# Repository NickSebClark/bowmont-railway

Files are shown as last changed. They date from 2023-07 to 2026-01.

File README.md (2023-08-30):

banner

Source code and designs for my model railway.

### Contents

[arduino-command](arduino-command/) | 
Central controller with servo shield. Connects to PC and arduino-remote.

[arduino-remote](arduino-remote/) | Handheld remote to control the points.

[pc-control](pc-control/) | Python app to control the points on PC.

[anyrail](anyrail/) | Track plan.

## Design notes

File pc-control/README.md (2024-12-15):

# Bowmont Railway PC Control



Uses pygame for animation. Communicates with Arduino using PySerial

Top-level: [main.py](pc_control/main.py).

Settings can be found in [settings.toml](settings.toml).

## Install

Dependencies are managed with [uv](https://docs.astral.sh/uv/). cd to the directory and get started with:

```shell
uv run main
```

The project is configured as a package. This tells uv to install pc_control as an editable package in the environment. This way, imports can always be relative to this package.

main.py is added as a script so we can access it easily with uv run.

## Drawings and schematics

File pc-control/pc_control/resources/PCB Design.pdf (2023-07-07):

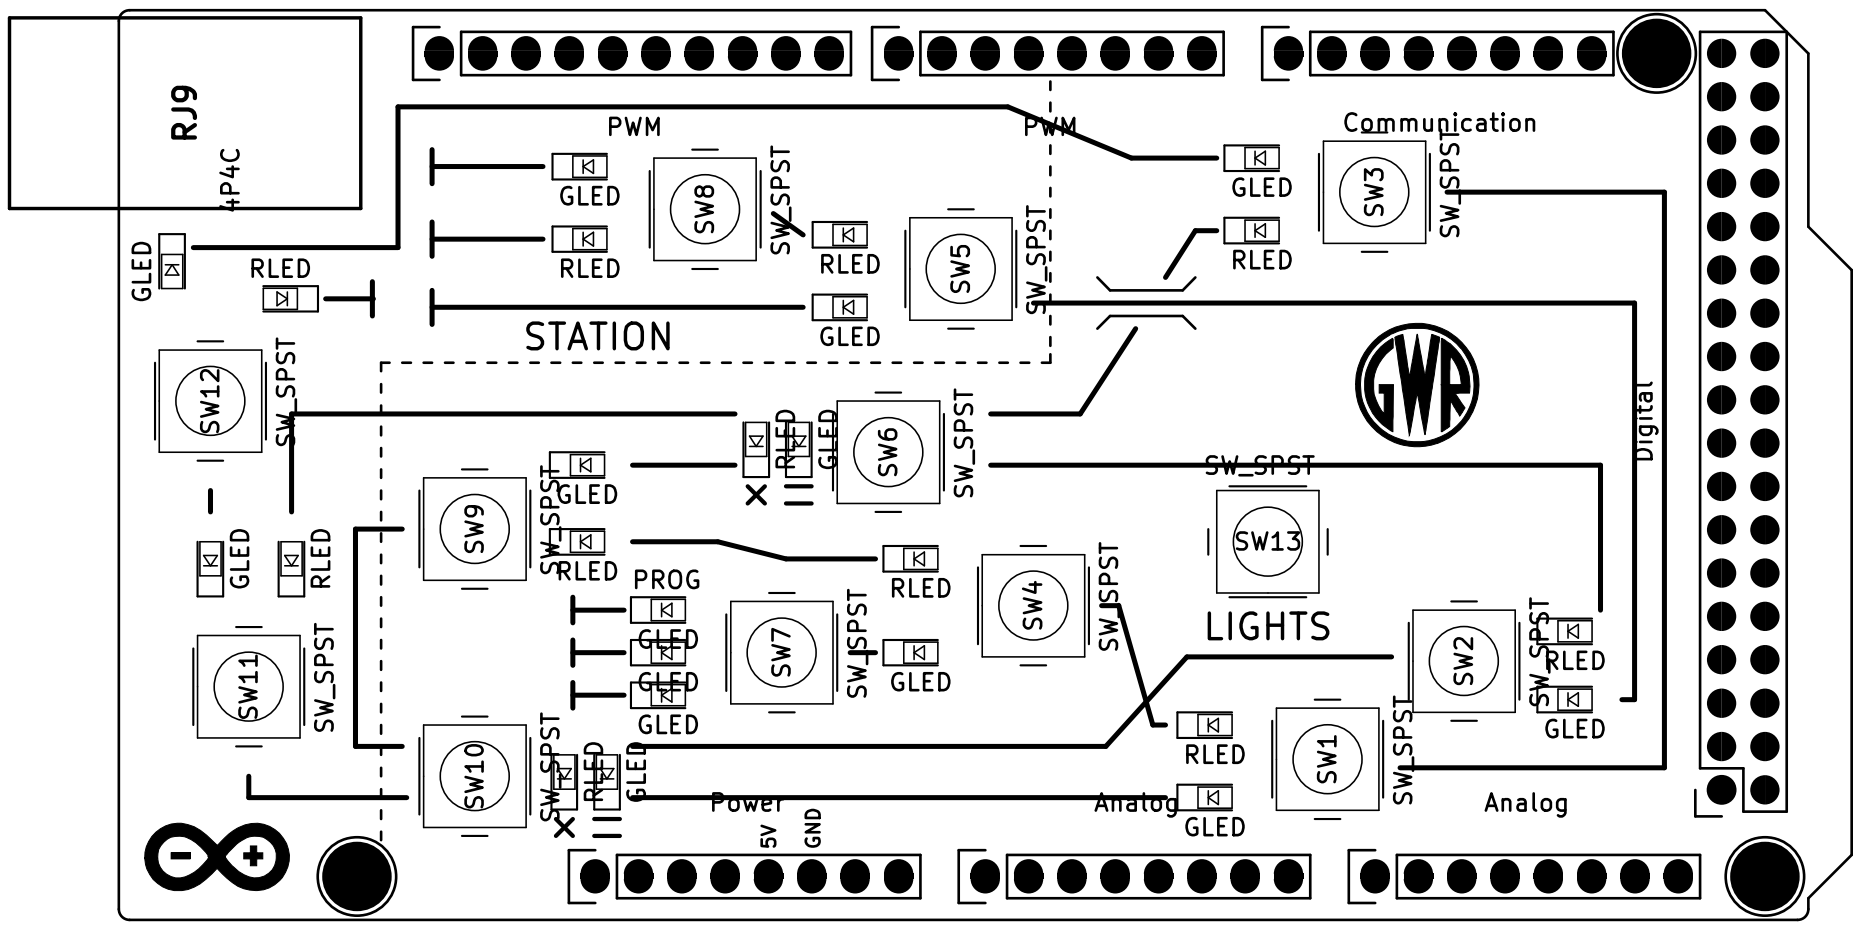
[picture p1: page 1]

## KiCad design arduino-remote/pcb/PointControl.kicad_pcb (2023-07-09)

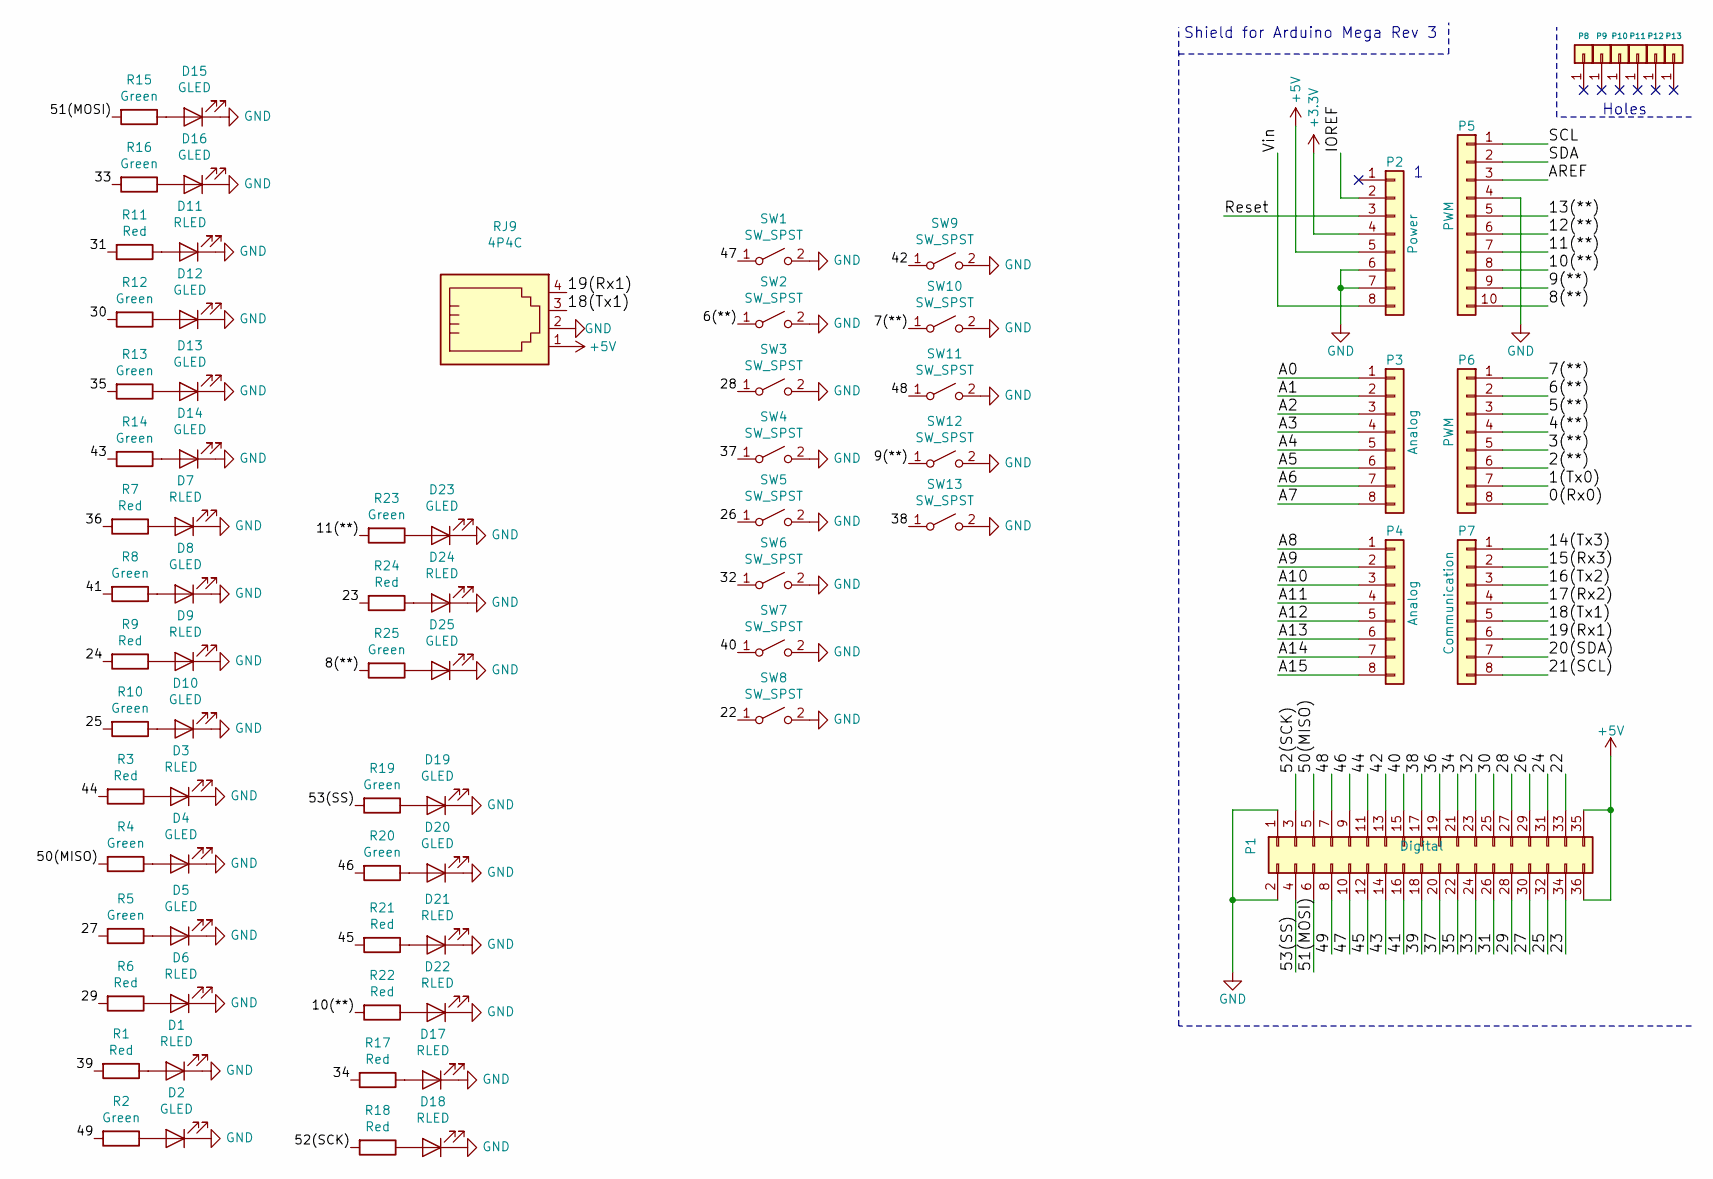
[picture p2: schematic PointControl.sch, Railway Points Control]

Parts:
D1, D3, D6, D7, D9, D11, D17, D18, D21, D22, D24: RLED; LED_0805_HandSoldering
D2, D4, D5, D8, D10, D12, D13, D14, D15, D16, D19, D20, D23, D25: GLED; LED_0805_HandSoldering
P1: Digital; Socket_Strip_Arduino_2x18
P2: Power; Socket_Strip_Arduino_1x08
P3, P4: Analog; Socket_Strip_Arduino_1x08
P5: PWM; Socket_Strip_Arduino_1x10
P6: PWM; Socket_Strip_Arduino_1x08
P7: Communication; Socket_Strip_Arduino_1x08
P8, P9, P10, P11, P12, P13: CONN_01X01; Arduino_1pin
R1, R3, R6, R7, R9, R11, R17, R18, R21, R22, R24: Red; R_0805_HandSoldering
R2, R4, R5, R8, R10, R12, R13, R14, R15, R16, R19, R20, R23, R25: Green; R_0805_HandSoldering
RJ9: 4P4C; MHRJJ44NFRA
SW1, SW2, SW3, SW4, SW5, SW6, SW7, SW8, SW9, SW10, SW11, SW12, SW13: SW_SPST; SW_PUSH_6mm

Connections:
+3V3: P2.4
+5V: P1.35, P1.36, P2.5, RJ9.1
/0(Rx0): P6.8
/1(Tx0): P6.7
/2(**): P6.6
/3(**): P6.5
/4(**): P6.4
/5(**): P6.3
/6(**): P6.2, SW2.1 (A)
/7(**): P6.1, SW10.1 (A)
/8(**): P5.10, R25.2
/9(**): P5.9, SW12.1 (A)
/10(**): P5.8, R22.2
/11(**): P5.7, R23.2
/12(**): P5.6
/13(**): P5.5
/14(Tx3): P7.1
/15(Rx3): P7.2
/16(Tx2): P7.3
/17(Rx2): P7.4
/18(Tx1): P7.5, RJ9.3
/19(Rx1): P7.6, RJ9.4
/20(SDA): P7.7
/21(SCL): P7.8
/22: P1.33, SW8.1 (A)
/23: P1.34, R24.2
/24: P1.31, R9.2
/25: P1.32, R10.2
/26: P1.29, SW5.1 (A)
/27: P1.30, R5.2
/28: P1.27, SW3.1 (A)
/29: P1.28, R6.2
/30: P1.25, R12.2
/31: P1.26, R11.2
/32: P1.23, SW6.1 (A)
/33: P1.24, R16.2
/34: P1.21, R17.2
/35: P1.22, R13.2
/36: P1.19, R7.2
/37: P1.20, SW4.1 (A)
/38: P1.17, SW13.1 (A)
/39: P1.18, R1.2
/40: P1.15, SW7.1 (A)
/41: P1.16, R8.2
/42: P1.13, SW9.1 (A)
/43: P1.14, R14.2
/44: P1.11, R3.2
/45: P1.12, R21.2
/46: P1.9, R20.2
/47: P1.10, SW1.1 (A)
/48: P1.7, SW11.1 (A)
/49: P1.8, R2.2
/50(MISO): P1.5, R4.2
/51(MOSI): P1.6, R15.2
/52(SCK): P1.3, R18.2
/53(SS): P1.4, R19.2
/A0: P3.1
/A1: P3.2
/A2: P3.3
/A3: P3.4
/A4: P3.5
/A5: P3.6
/A6: P3.7
/A7: P3.8
/A8: P4.1
/A9: P4.2
/A10: P4.3
/A11: P4.4
/A12: P4.5
/A13: P4.6
/A14: P4.7
/A15: P4.8
/AREF: P5.3
/IOREF: P2.2
/Reset: P2.3
/SCL: P5.1
/SDA: P5.2
/Vin: P2.8
GND: D1.1 (K), D2.1 (K), D3.1 (K), D4.1 (K), D5.1 (K), D6.1 (K), D7.1 (K), D8.1 (K), D9.1 (K), D10.1 (K), D11.1 (K), D12.1 (K), D13.1 (K), D14.1 (K), D15.1 (K), D16.1 (K), D17.1 (K), D18.1 (K), D19.1 (K), D20.1 (K), D21.1 (K), D22.1 (K), D23.1 (K), D24.1 (K), D25.1 (K), P1.1, P1.2, P2.6, P2.7, P5.4, RJ9.2, SW1.2 (B), SW2.2 (B), SW3.2 (B), SW4.2 (B), SW5.2 (B), SW6.2 (B), SW7.2 (B), SW8.2 (B), SW9.2 (B), SW10.2 (B), SW11.2 (B), SW12.2 (B), SW13.2 (B)
unnamed: D1.2 (A), R1.1
unnamed: D2.2 (A), R2.1
unnamed: D3.2 (A), R3.1
unnamed: D4.2 (A), R4.1
unnamed: D5.2 (A), R5.1
unnamed: D6.2 (A), R6.1
unnamed: D7.2 (A), R7.1
unnamed: D8.2 (A), R8.1
unnamed: D9.2 (A), R9.1
unnamed: D10.2 (A), R10.1
unnamed: D11.2 (A), R11.1
unnamed: D12.2 (A), R12.1
unnamed: D13.2 (A), R13.1
unnamed: D14.2 (A), R14.1
unnamed: D15.2 (A), R15.1
unnamed: D16.2 (A), R16.1
unnamed: D17.2 (A), R17.1
unnamed: D18.2 (A), R18.1
unnamed: D19.2 (A), R19.1
unnamed: D20.2 (A), R20.1
unnamed: D21.2 (A), R21.1
unnamed: D22.2 (A), R22.1
unnamed: D23.2 (A), R23.1
unnamed: D24.2 (A), R24.1
unnamed: D25.2 (A), R25.1

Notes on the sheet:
Shield for Arduino Mega Rev 3
Holes

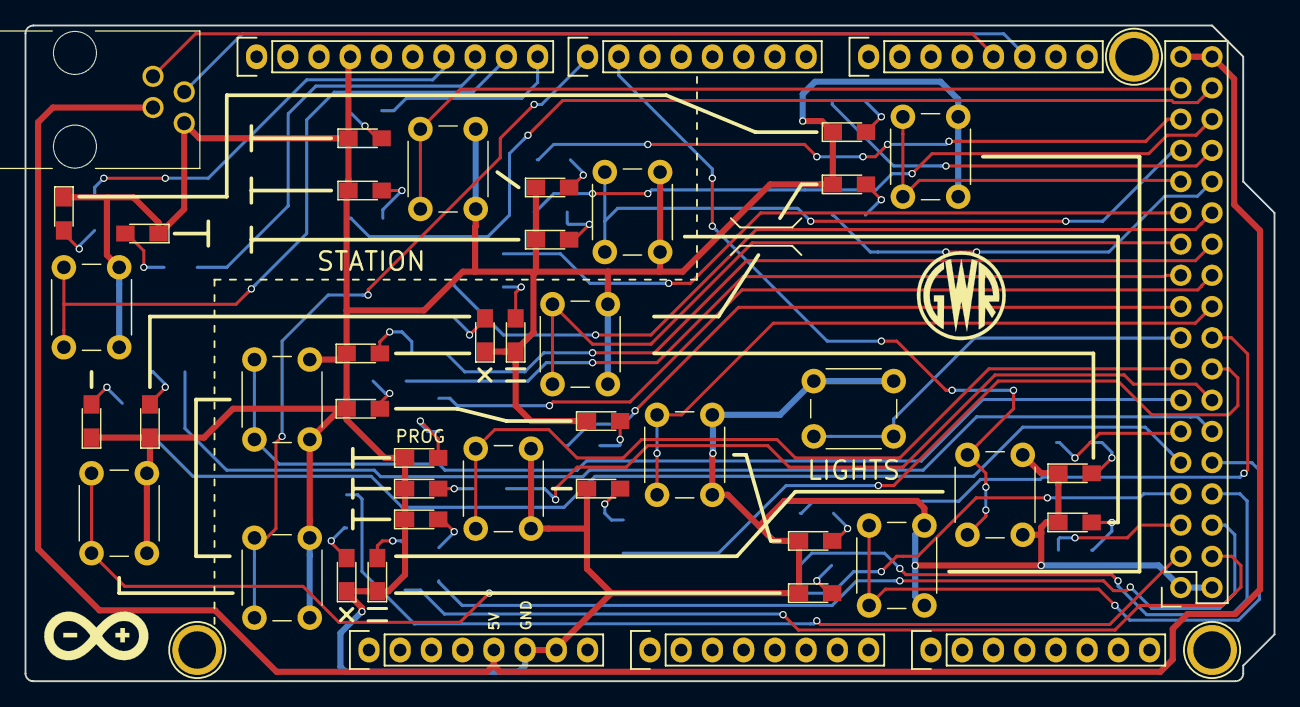
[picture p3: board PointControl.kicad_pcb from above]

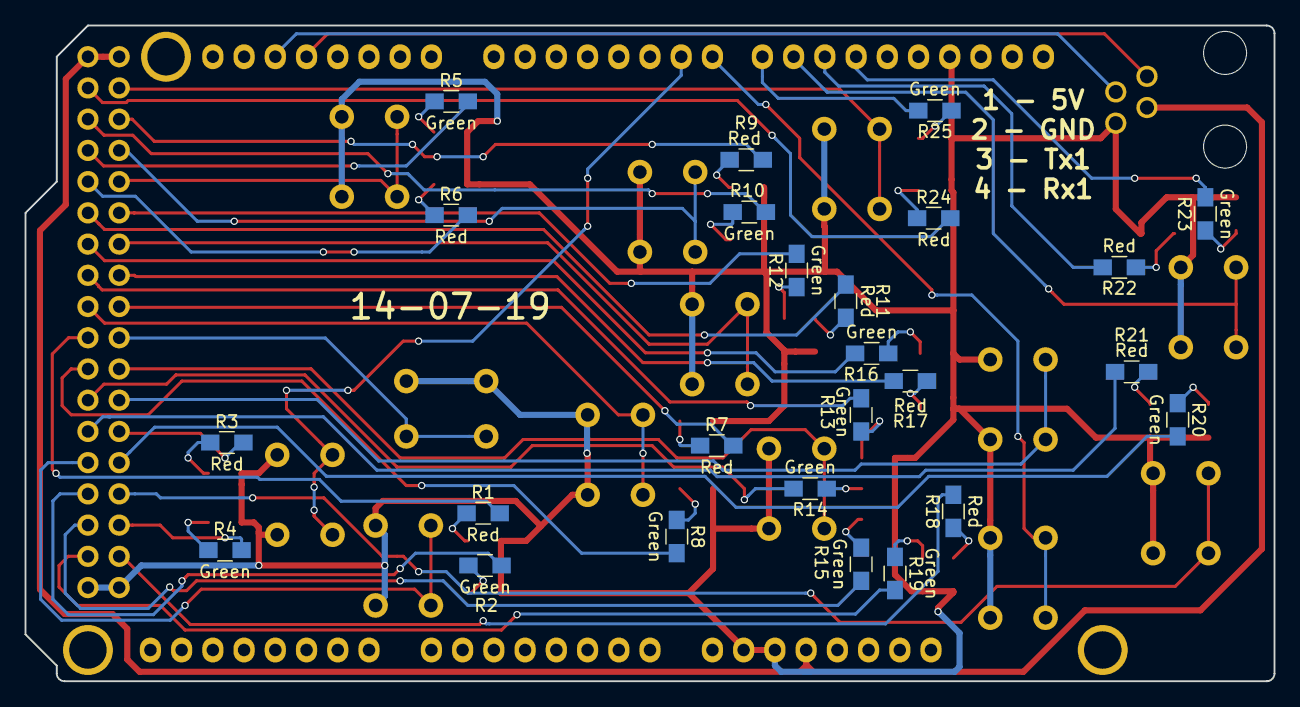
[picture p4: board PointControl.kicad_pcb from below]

Board: 2 copper layers, 101.6 x 53.3 mm, 74 parts (25 on the bottom side), 67 nets.

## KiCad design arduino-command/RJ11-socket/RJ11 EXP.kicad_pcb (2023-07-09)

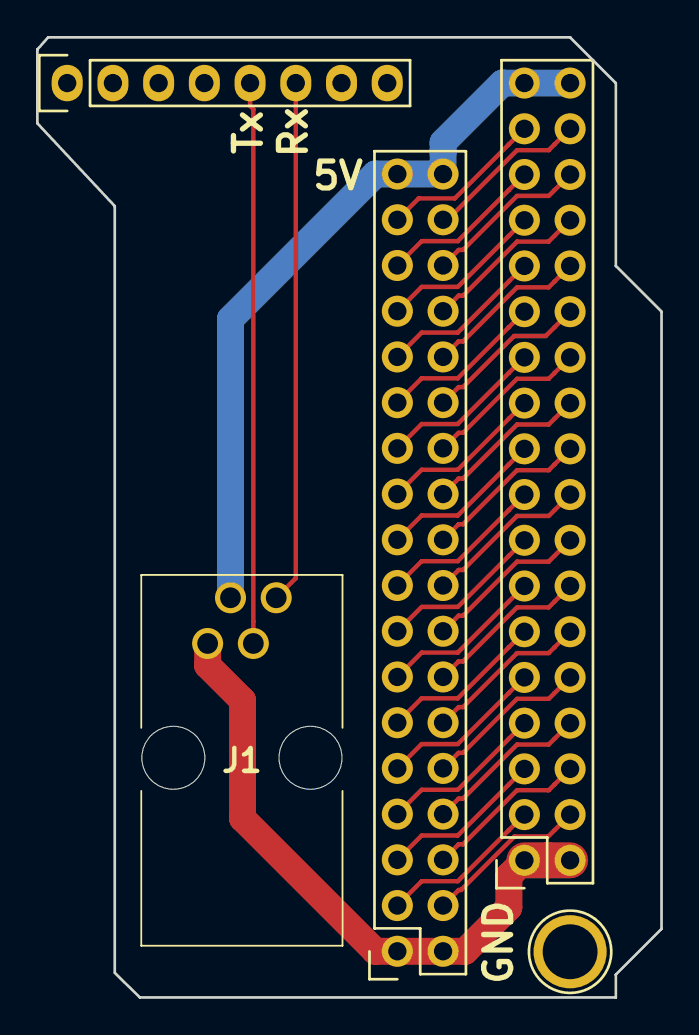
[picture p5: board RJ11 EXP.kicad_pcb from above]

Board: 2 copper layers, 34.7 x 53.3 mm, 5 parts (0 on the bottom side), 36 nets.

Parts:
J1: RJ9; MHRJJ44NFRA
P1, P14: Digital; Socket_Strip_Arduino_2x18
P7: Communication; Socket_Strip_Arduino_1x08
P10: CONN_01X01; Arduino_1pin

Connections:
+5V: J1.4, P1.35, P1.36, P14.35, P14.36
/18(Tx1): J1.1, P7.5
/19(Rx1): J1.2, P7.6
/22: P1.33, P14.33
/23: P1.34, P14.34
/24: P1.31, P14.31
/25: P1.32, P14.32
/26: P1.29, P14.29
/27: P1.30, P14.30
/28: P1.27, P14.27
/29: P1.28, P14.28
/30: P1.25, P14.25
/31: P1.26, P14.26
/32: P1.23, P14.23
/33: P1.24, P14.24
/34: P1.21, P14.21
/35: P1.22, P14.22
/36: P1.19, P14.19
/37: P1.20, P14.20
/38: P1.17, P14.17
/39: P1.18, P14.18
/40: P1.15, P14.15
/41: P1.16, P14.16
/42: P1.13, P14.13
/43: P1.14, P14.14
/44: P1.11, P14.11
/45: P1.12, P14.12
/46: P1.9, P14.9
/47: P1.10, P14.10
/48: P1.7, P14.7
/49: P1.8, P14.8
/50(MISO): P1.5, P14.5
/51(MOSI): P1.6, P14.6
/52(SCK): P1.3, P14.3
/53(SS): P1.4, P14.4
GND: J1.3, P1.1, P1.2, P14.1, P14.2

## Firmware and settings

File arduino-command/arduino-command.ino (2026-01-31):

#include <Adafruit_PWMServoDriver.h>

#include <TimerThree.h>

#include <Wire.h>
#include <Adafruit_PWMServoDriver.h>

#define NBR_POINTS 15

#define Control_switch 44


// min = 200
// max = 300 

// the counter number for each servo
// look at the diagram on Python. The buttons are labelled
#define servo_0 14   // Button 0
#define servo_1 6   // Button 1
#define servo_2 8   // Button 2
#define servo_3 2  // Button 3
#define servo_4 1  // Button 3
#define servo_5 15   // Button 4 #TESTTEST
#define servo_6 4  // Button 5
#define servo_7 5  // Button 5
#define servo_8 10  // Button 6
#define servo_9 9   // Button 6
#define servo_10 7  // Button 7 INCREMENT TEST
#define servo_11 3  // Button 8
#define servo_12 11 // Button 9
#define servo_13 12 // Button 10
#define servo_14 13 // Button 11

#define servo_0_pos0 326
#define servo_1_pos0 275
#define servo_2_pos0 340
#define servo_3_pos0 350
#define servo_4_pos0 200
#define servo_5_pos0 275
#define servo_6_pos0 350
#define servo_7_pos0 362
#define servo_8_pos0 279
#define servo_9_pos0 324
#define servo_10_pos0 395
#define servo_11_pos0 350
#define servo_12_pos0 276
#define servo_13_pos0 275
#define servo_14_pos0 290

#define servo_0_pos1 276
#define servo_1_pos1 376
#define servo_2_pos1 278
#define servo_3_pos1 200
#define servo_4_pos1 275
#define servo_5_pos1 358
#define servo_6_pos1 285
#define servo_7_pos1 299
#define servo_8_pos1 324
#define servo_9_pos1 276
#define servo_10_pos1 275
#define servo_11_pos1 283
#define servo_12_pos1 340
#define servo_13_pos1 350
#define servo_14_pos1 340

Adafruit_PWMServoDriver pwm = Adafruit_PWMServoDriver();

char inCmd[6];
int cmdPos = 0;

int pointStatus[NBR_POINTS];
int pointServo[NBR_POINTS] = {servo_0, servo_1, servo_2, servo_3, servo_4, servo_5, servo_6, servo_7, servo_8, servo_9, servo_10, servo_11, servo_12, servo_13, servo_14};
int pointPos0[NBR_POINTS] = {servo_0_pos0, servo_1_pos0, servo_2_pos0, servo_3_pos0, servo_4_pos0, servo_5_pos0, servo_6_pos0, servo_7_pos0, servo_8_pos0, servo_9_pos0, servo_10_pos0, servo_11_pos0, servo_12_pos0, servo_13_pos0, servo_14_pos0};
int pointPos1[NBR_POINTS] = {servo_0_pos1, servo_1_pos1, servo_2_pos1, servo_3_pos1, servo_4_pos1, servo_5_pos1, servo_6_pos1, servo_7_pos1, servo_8_pos1, servo_9_pos1, servo_10_pos1, servo_11_pos1, servo_12_pos1, servo_13_pos1, servo_14_pos1};
int point_pair[NBR_POINTS] = {0, 0, 0, 1, -1, 0, 0, 0, 1, -1, 0, 0, 0, 0, 0}; // shows the offset, if any, to a partner in a point pair.
int pointPos[NBR_POINTS];

boolean stringRecieved = false;

String syncString;

void incrementPosition(int point)
{
  pointPos[point]++;

  pwm.setPWM(pointServo[point], 0, pointPos[point]);

  Serial.print("<Increment point in Arduino, Point: ");
  Serial.print(point);
  Serial.print(" Val: ");
  Serial.print(pointPos[point]);
  Serial.print(">\n");
}

void decrementPosition(int point)
{
  pointPos[point]--;

  pwm.setPWM(pointServo[point], 0, pointPos[point]);

  Serial.print("<Decrement point in Arduino, Point: ");
  Serial.print(point);
  Serial.print(" Val: ");
  Serial.print(pointPos[point]);
  Serial.print(">\n");
}

void setup()
{
  Serial.begin(9600); // init comm
  Serial1.begin(9600);

  pwm.begin();
  pwm.setPWMFreq(50);

  memcpy(pointPos, pointPos0, sizeof(pointPos0));

  for (int i = 0; i < NBR_POINTS; i++)
  {
    pointStatus[i] = 0;
    setPoint(i, false);
  }
  syncData();

  Timer3.initialize(20000000);
  Timer3.attachInterrupt(sendHeartBeat);
}

void loop()
{
}

void parseString()
{
  Serial.print("<Parsing Input String>\n");
  
  int point_index;

  switch (inCmd[0])
  {
  case 'p':

    point_index = indexFromString();

    // set the point pair too if it exists. We only update on the seconf of the pair
    if (point_pair[point_index] != 0){ 
      setPoint(point_index, false);
      setPoint(point_index + point_pair[point_index], true);
    }
    else
      setPoint(point_index, true);

    break;
  case 's':
    setSignal(inCmd[2]);
    break;
  case 'l':
    toggleLights();
    break;
  case 'c':
    sendHeartBeat();
    break;
  case 'r':
    syncData();
    break;
  case 'i':
    incrementPosition(indexFromString());
    break;
  case 'd':
    decrementPosition(indexFromString());
    break;
  default:
    Serial.println("<Command not found>");
    break;
  }
}

int indexFromString()
{
  String s;
  if (cmdPos > 2)
  { // two character number
    s = String(inCmd[1]) + String(inCmd[2]);
    return s.toInt();
  }
  else
    return (int)inCmd[1] - 48;
}



void serialEvent1()
{
  while (Serial1.available())
  {
    int i;

    char inChar = (char)Serial1.read();

    // add it to the inputString:
    inCmd[cmdPos] = inChar;
    cmdPos++;

    // if the incoming character is a newline, we have a whole command. Do something.
    if (inChar == '\n')
    {
      Serial.println("<Serial-1 Recieved>");
      for (i = 0; i < cmdPos; i++)
      {
        Serial.print(inCmd[i]);
      }
      parseString();
      cmdPos = 0;
    }
  }
}

void serialEvent()
{ // reads from the serial port
  while (Serial.available())
  {
    int i;
    char inChar = (char)Serial.read();

    // add it to the inputString:
    inCmd[cmdPos] = inChar;
    cmdPos++;

    // if the incoming character is a newline, we have a whole command. Do something.
    if (inChar == '\n')
    {
      Serial.println("<Serial Recieved>");
      for (i = 0; i < cmdPos; i++)
      {
        Serial.print(inCmd[i]);
      }
      parseString();
      cmdPos = 0;
    }
  }
}

void sendHeartBeat()
{
  Serial.print("<ID: 18/01/25 v2.3>\n");
}

void setPoint(int point, bool sync)
{ // toggles status of point

  if (pointServo[point] > -2)
  {
    if (pointStatus[point])
    {
      Serial.print("<Setting point in Arduino, Point: ");
      Serial.print(point);
      Serial.print(" Val: ");
      Serial.print(pointPos0[point]);
      Serial.print(">\n");
      pwm.setPWM(pointServo[point], 0, pointPos0[point]);
      pointStatus[point] = 0;
      pointPos[point] = pointPos0[point];
    }
    else
    {
      Serial.print("<Setting point in Arduino, Point: ");
      Serial.print(point);
      Serial.print(" Val: ");
      Serial.print(pointPos1[point]);
      Serial.print(">\n");
      pwm.setPWM(pointServo[point], 0, pointPos1[point]);
      pointStatus[point] = 1;
      pointPos[point] = pointPos1[point];
    }
  }
  delay(1000);
  pwm.setPWM(pointServo[point], 0, 0);

  if (sync){
    syncData();
  }
}

void syncData()
{
  syncString = "S";
  for (int k = 0; k < NBR_POINTS; k++)
  {
    syncString = syncString + String(pointStatus[k]);
  }
  // send to both serial ports so PC/controller swap is seamless.
  Serial.println(syncString);
  Serial1.println(syncString);
}

void setSignal(int sig)
{
  Serial.println("<Signals...>");
  syncData();
}

void toggleLights()
{
  Serial.println("<Lights Toggled>");
  syncData();
}

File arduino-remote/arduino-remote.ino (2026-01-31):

#define NBR_SERVOS 15
#define NBR_POINT_BUTTONS 12

// led pins for each point
int ledpins[][2] = {{10, 11},
                    {45, 46},
                    {34, 33},
                    {52, 53},
                    {8, 23},
                    {-1, -1},
                    {31, 30},
                    {24, 25},
                    {36, 41},
                    {29, 27},
                    {39, 49},
                    {44, 50}};

// LED pins for the tristate button
int ledpins_tri[] = {35, 43, 51};
int button_pins[] = {9, 48, 42, 7, 22, 40, 32, 26, 37, 28, 47, 6, 38};

const int flash_wait = 200;

int servo_point[] = {0, 1, 2, 3, 3, 4, 5, 5, 6, 6, 7, 8, 9, 10, 11}; // defines which point a particular servo is changing. I.e. when a servo changes which light should we change.
int point_servo[] = {0, 1, 2, 3, 5, 6, 8, 10, 11, 12, 13, 14};       // what servo to switch for a particular point, the controller handles point pairs)
int servo_6_set;
int servo_7_set;

int i = 0;

int buttonState[NBR_POINT_BUTTONS + 1];     // the current reading from the input pin
int lastButtonState[NBR_POINT_BUTTONS + 1]; // the previous reading from the input pin

// the following variables are unsigned longs because the time, measured in
// milliseconds, will quickly become a bigger number than can be stored in an int.
unsigned long lastDebounceTime[NBR_POINT_BUTTONS + 1]; // the last time the output pin was toggled
unsigned long debounceDelay = 100;                     // the debounce time; increase if the output flickers
unsigned long previousMillis = 0;                      // will store last time LED was updated

char inCmd[25];
int cmdPos = 0;
bool startup = true;

void setup()
{

  // set the digital pin as output:
  for (i = 0; i < NBR_POINT_BUTTONS; i++)
  {
    pinMode(ledpins[i][0], OUTPUT);
    digitalWrite(ledpins[i][0], LOW);

    pinMode(ledpins[i][1], OUTPUT);
    digitalWrite(ledpins[i][1], LOW);

    pinMode(ledpins_tri[0], OUTPUT);
    digitalWrite(ledpins_tri[0], LOW);
    pinMode(ledpins_tri[1], OUTPUT);
    digitalWrite(ledpins_tri[1], LOW);
    pinMode(ledpins_tri[2], OUTPUT);
    digitalWrite(ledpins_tri[2], LOW);

    pinMode(button_pins[i], INPUT_PULLUP);
  }

  pinMode(button_pins[NBR_POINT_BUTTONS], INPUT_PULLUP);

  circleLights();

  // set all the button states to false
  memset(lastButtonState, 0, sizeof(lastButtonState));

  // initialize serial:
  Serial1.begin(9600);
  Serial.begin(9600);

  requestSync();
}

void requestSync()
{ // send a message to the points controller to request a synchronisation
  Serial1.write("r\n");
}

void flashLights(int wait)
{
  for (i = 0; i < NBR_POINT_BUTTONS; i++)
  {
    digitalWrite(ledpins[i][0], HIGH);
    digitalWrite(ledpins[i][1], HIGH);
    if (i == 5)
    {
      digitalWrite(ledpins_tri[0], HIGH);
      digitalWrite(ledpins_tri[1], HIGH);
      digitalWrite(ledpins_tri[2], HIGH);
    }
  }

  delay(wait);

  for (i = 0; i < NBR_POINT_BUTTONS; i++)
  {
    digitalWrite(ledpins[i][0], LOW);
    digitalWrite(ledpins[i][1], LOW);
    if (i == 5)
    {
      digitalWrite(ledpins_tri[0], LOW);
      digitalWrite(ledpins_tri[1], LOW);
      digitalWrite(ledpins_tri[2], LOW);
    }
  }

  delay(wait);
}

void circleLights()
{

  for (i = 0; i < NBR_POINT_BUTTONS; i++)
  { // circle around all the lights
    if (i == 5)
    {
      digitalWrite(ledpins_tri[0], LOW);
      digitalWrite(ledpins_tri[1], LOW);
      digitalWrite(ledpins_tri[2], LOW);
    }
    else
    {
      digitalWrite(ledpins[i][0], LOW);
      digitalWrite(ledpins[i][1], LOW);
    }
  }

  for (i = 0; i < NBR_POINT_BUTTONS; i++)
  { // circle around all the lights
    if (i == 5)
    {
      digitalWrite(ledpins_tri[0], HIGH);
      delay(flash_wait);
      digitalWrite(ledpins_tri[0], LOW);
      digitalWrite(ledpins_tri[1], HIGH);
      delay(flash_wait);
      digitalWrite(ledpins_tri[1], LOW);
      digitalWrite(ledpins_tri[2], HIGH);
      delay(flash_wait);
      digitalWrite(ledpins_tri[2], LOW);
    }
    else
    {
      digitalWrite(ledpins[i][0], HIGH);
      delay(flash_wait);
      digitalWrite(ledpins[i][0], LOW);
      digitalWrite(ledpins[i][1], HIGH);
      delay(flash_wait);
      digitalWrite(ledpins[i][1], LOW);
    }
  }
}

void setPointLight(int button_index, int state)
{
  if (button_index == 5)
  {
    switch (state)
    {
    case 0:
      digitalWrite(ledpins_tri[0], HIGH);
      digitalWrite(ledpins_tri[1], LOW);
      digitalWrite(ledpins_tri[2], LOW);
      break;
    case 1:
      digitalWrite(ledpins_tri[0], LOW);
      digitalWrite(ledpins_tri[1], HIGH);
      digitalWrite(ledpins_tri[2], LOW);
      break;
    case 2:
      digitalWrite(ledpins_tri[0], LOW);
      digitalWrite(ledpins_tri[1], LOW);
      digitalWrite(ledpins_tri[2], HIGH);
      break;
    }
  }
  else
  {
    digitalWrite(ledpins[button_index][0], state);
    digitalWrite(ledpins[button_index][1], !state);
  }
}

void updatePointState(int servo_index, int state)
{
  // map from the servo to the point state
  int point_index;
  Serial.println("Update State: " + String(servo_index) + " State =" + String(state));

  point_index = servo_point[servo_index]; // find which point to change for this servo.

  if (servo_index == 6)
  {
    servo_6_set = state; // save this as servo 7 state is irrelevant if this is set.
    if (state)
    {
      state = 2; // set the bottom siding
    }
  }
  else if (servo_index == 7)
  {
    servo_7_set = state;
    if (servo_6_set)
    {
      state = 2; // set the bottom siding in the 3 if servo 6 is set,o therwise servo 7 indicates middle siding
    }
  }

  setPointLight(point_index, state);
}

void requestPointChange(int button_index)
{
  // map from the button to the servo_index
  int index = point_servo[button_index];

  Serial.println("Request change button index: " + String(button_index) + " Servo Index: " + String(index));

  if (button_index == 5)
  { // some special code for the tristate point as we need to control p6 and p7
    if (servo_6_set)
    { // state is 2 so change to state 0
      Serial1.println("p6");
      if (!servo_7_set)
      {
        Serial1.println("p7");
      }
    }
    else if (servo_7_set)
    { // state 0 so change to state 1
      Serial1.println("p7");
    }
    else
    { // state 1 so change to state 2
      Serial1.println("p6");
    }
  }
  else
  {
    Serial1.println("p" + String(index)); // point pairs are handled by the points controller
  }
}
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

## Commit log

2022-03-25 Added Arduino Source
2023-07-07 Added endstops to track sections
2023-07-07 Docstring for Track
2023-07-08 Added a load of track
2023-07-09 Add Triple Point, AA, Bridge, Track adjustments
2023-07-09 Added a load of files
    [PointControl.kicad_pcb, PointControl.sch, RJ11 EXP.kicad_pcb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]
2023-07-10 Label positions, track fettling.
2023-07-25 Parsing of serial synchronisation. Organisation of points to match PCB.
2023-07-27 Added request sync button
2023-08-11 Remove flash lights
    Too much current draw.
    [arduino-remote.ino]
2023-08-28 Added catch for no serial. Added rounded corners for track.
2025-06-21 Servo settings
2025-07-13 Update arduino-command.ino
    servo values
2025-10-18 More servos.
    Update for triple.
2026-01-18 Servo tweaking
2026-01-31 Got all the directions correct.
    [arduino-command.ino, arduino-remote.ino]
